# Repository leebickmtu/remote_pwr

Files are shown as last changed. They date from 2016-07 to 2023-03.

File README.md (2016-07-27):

Remote Power (RPi HAT)
=========================
Remotely query/change the power state of a computer from an always on, low power Raspberry Pi.

Intended to be used over SSH to control the power state of a desktop computer.

Includes EAGLE board schematic for a RPi Zero HAT which the computer's front panel header connect to. And python scripts which can then be executed on the RPi to query/change the power state of the connected computer.

EAGLE board and schematic
--------
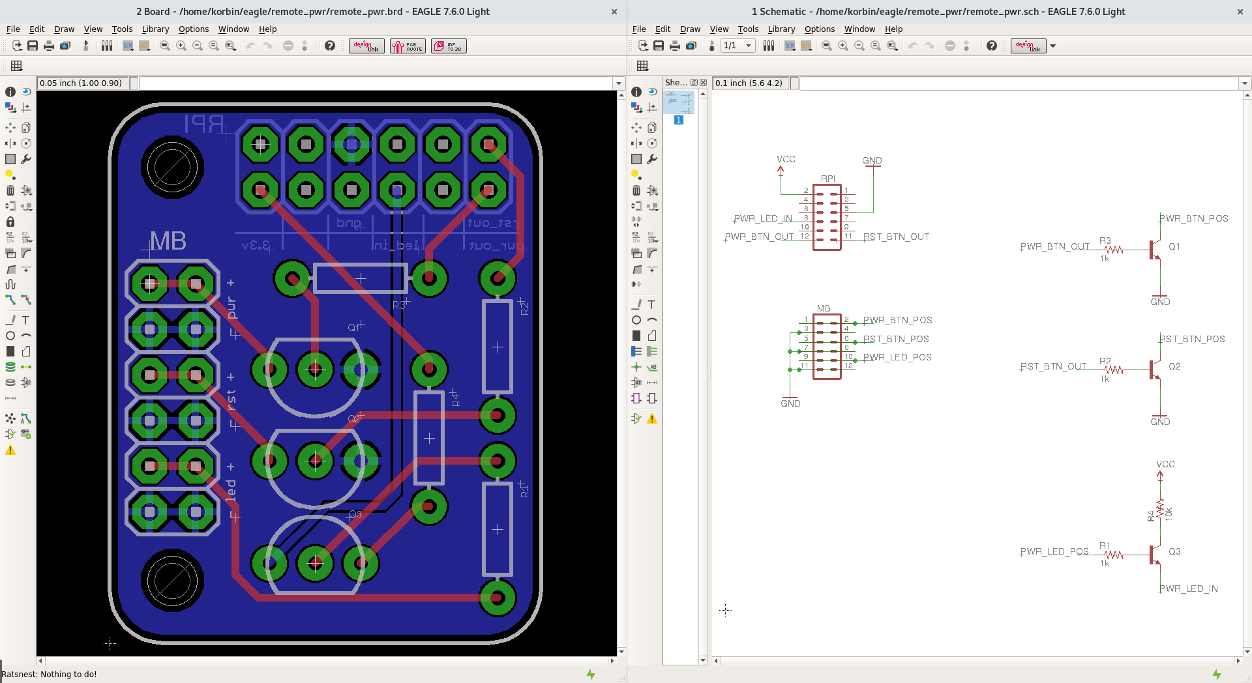
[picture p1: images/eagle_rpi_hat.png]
EAGLE board and schematic

RPi Zero with HAT

Python script use
--------
```bash
# Query the power state (returns 'sleep', 'on', 'off')
./remote_pwr state

# "Push" the power or reset buttons
./remote_pwr pulse pwr
./remote_pwr pulse rst

# "Hold" the power button
./remote_pwr hold pwr
```

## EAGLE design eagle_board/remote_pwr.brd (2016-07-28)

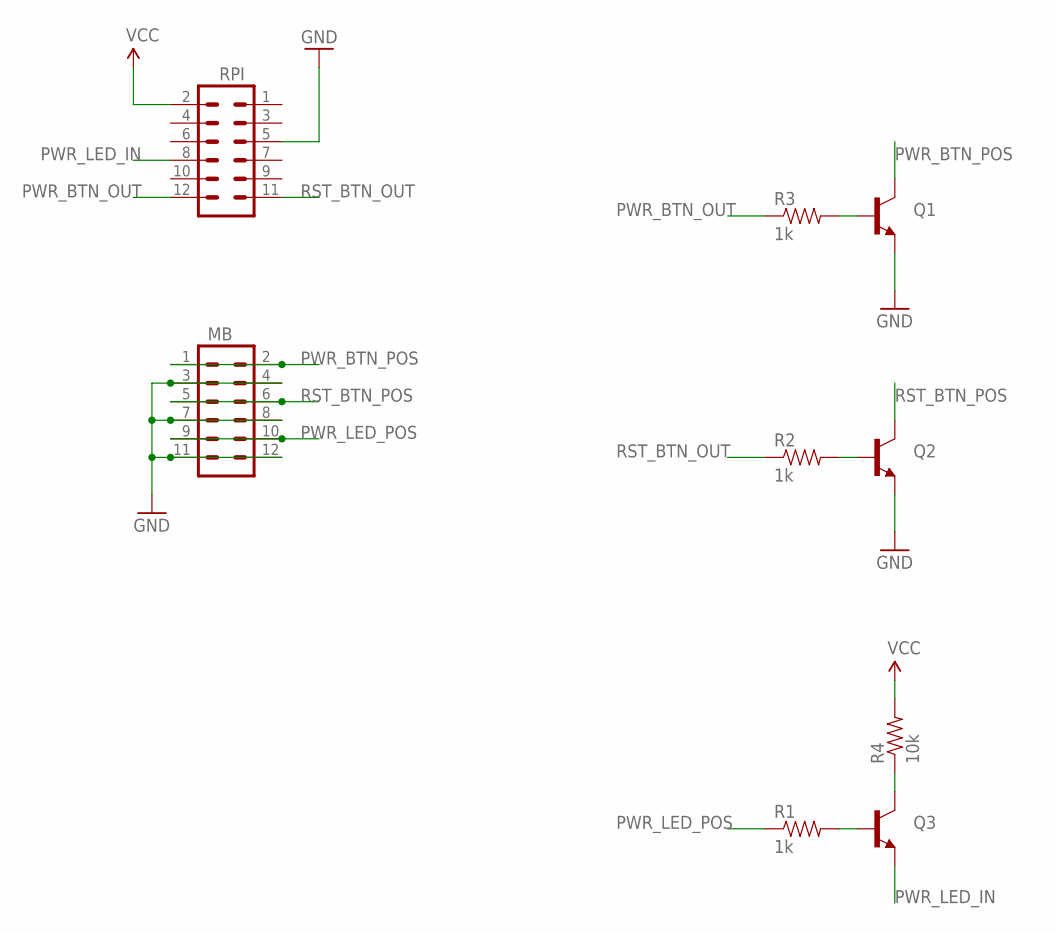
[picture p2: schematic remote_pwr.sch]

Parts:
MB: M06X2PTH_FEMALE; 2X6
Q1, Q2, Q3: TRANSISTOR_NPNTO-92-AMMO; TO-92-AMMO
R1, R2, R3: 1k; AXIAL-0.3
R4: 10k; AXIAL-0.3
RPI: M06X2PTH_FEMALE; 2X6

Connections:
GND: MB.3, MB.4, MB.7, MB.8, MB.11, MB.12, Q1.1 (E), Q2.1 (E), RPI.5
unnamed: Q3.3 (C), R4.P$1 (1)
unnamed: Q1.2 (B), R3.P$2 (2)
unnamed: Q2.2 (B), R2.P$2 (2)
unnamed: Q3.2 (B), R1.P$2 (2)
PWR_BTN_OUT: R3.P$1 (1), RPI.12
PWR_BTN_POS: MB.1, MB.2, Q1.3 (C)
PWR_LED_IN: Q3.1 (E), RPI.8
PWR_LED_POS: MB.9, MB.10, R1.P$1 (1)
RST_BTN_OUT: R2.P$1 (1), RPI.11
RST_BTN_POS: MB.5, MB.6, Q2.3 (C)
VCC: R4.P$2 (2), RPI.2

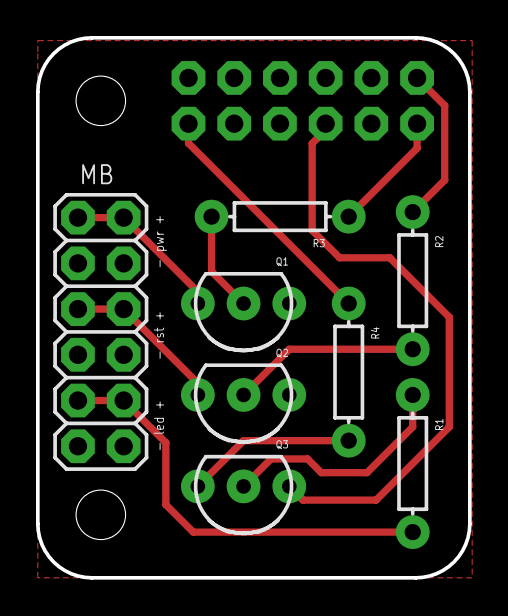
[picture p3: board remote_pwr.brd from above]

Board: 2 copper layers, 24.0 x 30.0 mm, 9 parts (1 on the bottom side), 12 nets.

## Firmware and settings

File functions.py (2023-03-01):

import RPi.GPIO as GPIO
import time

pins = {'pwr':11, 'rst':12, 'led':7}

def hold(button):
	pin = (pins[button])

	try:
		GPIO.setmode(GPIO.BOARD)
		GPIO.setup(pin, GPIO.OUT)

		GPIO.output(pin, True)
		time.sleep(5)
		GPIO.output(pin, False)

	finally:
		GPIO.cleanup()

def pulse(button):
	pin = (pins[button])

	try:
		GPIO.setmode(GPIO.BOARD)
		GPIO.setup(pin, GPIO.OUT)

		GPIO.output(pin, True)
		time.sleep(.1)
		GPIO.output(pin, False)

	finally:
		GPIO.cleanup()

def pwr_state():
	pin = (pins['led'])

	try:
		GPIO.setmode(GPIO.BOARD)
		GPIO.setup(pin, GPIO.IN, pull_up_down=GPIO.PUD_DOWN)
	
		class Counter(object):
			def __init__(self, start=0):
				self.x = start
			def __call__(self, channel):
				self.x += 1
				return self.x
		
		count = Counter()
		
		GPIO.add_event_detect(pin, GPIO.RISING)
		GPIO.add_event_callback(pin, count)
		
		time.sleep(1.2)
		GPIO.remove_event_detect(pin)
		
		if (count.x > 0):
			print("sleep")
		elif (GPIO.input(pin)):
			print("on")
		else:
			print("off")
	
	finally:
		GPIO.cleanup()

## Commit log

2016-07-27 Add project files
    [remote_pwr.brd, remote_pwr.sch]
2016-07-27 Add image of EAGLE schematic and board
2016-07-27 Update README.md
    Note that the RPi HAT footprint is designed for the RPi Zero.
2016-07-28 Update EAGLE board
    Change board to have all traces and ground plane on single side.
    [remote_pwr.brd]
2016-07-28 Update EAGLE board
    Revert to old layout but still move traces to single side.
    [remote_pwr.brd]
2016-09-21 Update LICENSE
    Switch from GPL to Unlicense going forward.

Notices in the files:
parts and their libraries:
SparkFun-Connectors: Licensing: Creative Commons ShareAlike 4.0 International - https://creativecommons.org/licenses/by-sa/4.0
